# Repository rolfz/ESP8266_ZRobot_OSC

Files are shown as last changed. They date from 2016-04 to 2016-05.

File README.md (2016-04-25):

# ESP8266_ZRobot_OSC

EPS8266 based Robot with OSC based remote control. Robot can be controlled by iPhone or Smartphone, both config files are included.
The robot was based on FTobler Thingiverse 3d design http://www.thingiverse.com/thing:1230244

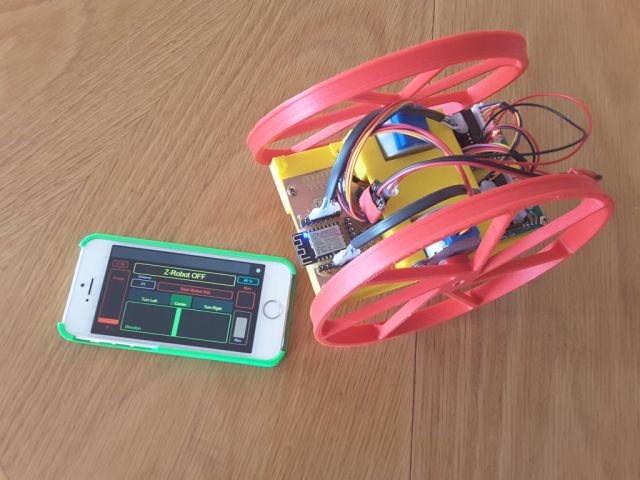
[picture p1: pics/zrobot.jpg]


Functionality: The robot code was basically made to test the TOUCHOSC interface. OSC allows to communicate both 
	ways between ESP8266 and a smart-phone. All code runs on the ESP module (No Arduino Hardware required).
- "Speed" cursor will define the speed of the step motors advance.
- "Direction" cursor adds or deducts a value from the speed making the robot turn left-right
- "Reverse" button inverses the motor rotation = reverse the engine direction like a car.
- 3 buttons "Turn Left, Center, Turn right" are preprogrammed directions for the robot
- "RUN" button will start the engine and also stop everything if cancelled.
- One status line is used to send instructions to the pilot
- One distance message box will indicate the distance to the next object (to be implemented).
- Current time and Smartphone battery are shown on the display

### Basic ideas, origin of the project:

- ftobler 3d files printed on Lulzbot TAZ4 printer.
- two 28byj-48 stepper motors with driver circuit from ebay
- ESP8266 12E module
	
###Changes, additions:

- ESP was programmed with Arduino based environment and ESP plug-in
- Accelstepper library (http://www.airspayce.com/mikem/arduino/AccelStepper/).
- Tutorial can be found here: (https://www.pjrc.com/teensy/td_libs_AccelStepper.html).
- LV-MAXSonar-EZ0 from Sparkfun
- self made board to hold the ESP module, with 2 push buttons for reset and setting programming mode, 
  led and connectors for the peripherals.
- Alternative battery holder to hold a 2S Lipo
- Alternative motor connections to simplify the wiring on the self made board.

### TouchOSC:

I discovered this app by accident when I looked at B-Robot and similar projects. Some tests made with 
Blynk which looks even more attractive made visible the current advantage of OSC! Easy implementation,
easy to use windows application to create the GUI, easy to load on a second or alternative platform 
and sizable widgets which are not yet possible on Blynk made me keep OSC for this project. Maybe I 
missed something on Blynk, at least it was not immediately visible that the features I missed where 
available. TouchOSC design tool is available for free from http://hexler.net/software/touchosc, you 
will need to pay for the user interface you download on your phone or tablet.

My current TouchOSC design:

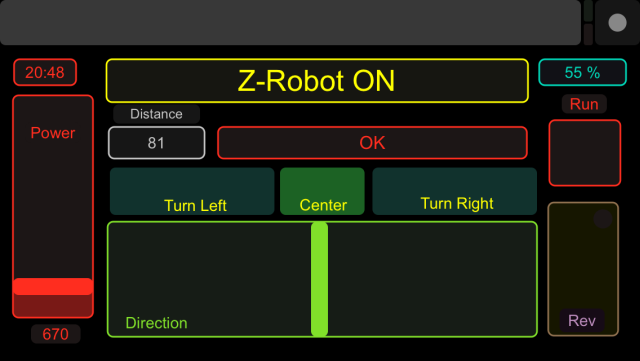
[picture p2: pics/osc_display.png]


OSC config: 
----------
Simple-Z-Robot-Iphone5.touchosc
Simple-Z-Robot-Samsung.touchosc
	
Code:
----
ESP8266_ZRobot_OSC.ino includes all Zrobot specific code.

Schematic:
---------
[schematic.pdf](schematic.pdf) and eagle files

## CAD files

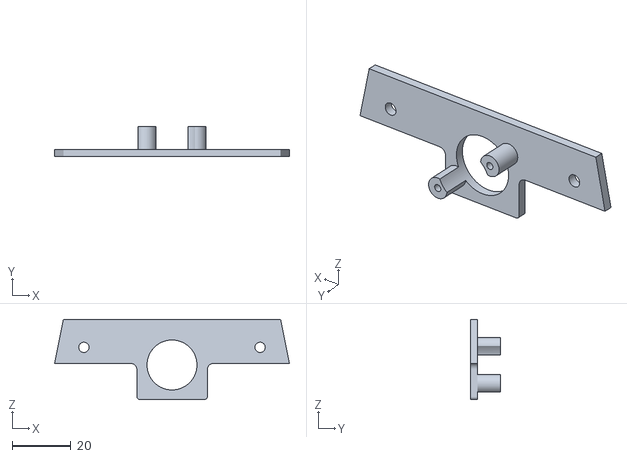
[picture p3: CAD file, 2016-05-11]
hardware/Ultrasonic_mounting.stl
80.0 x 10.3 x 27.3

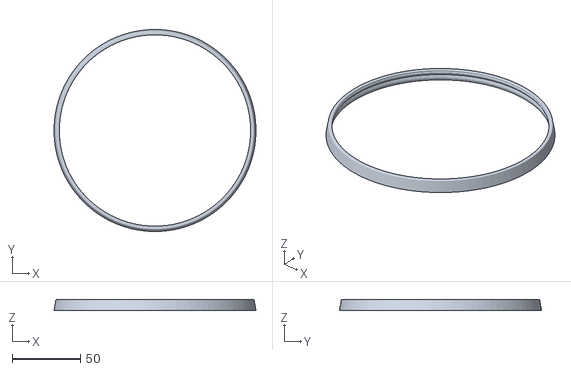
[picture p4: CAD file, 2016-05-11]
hardware/tyre_ninja.v2.stl
147.9 x 147.9 x 8.31

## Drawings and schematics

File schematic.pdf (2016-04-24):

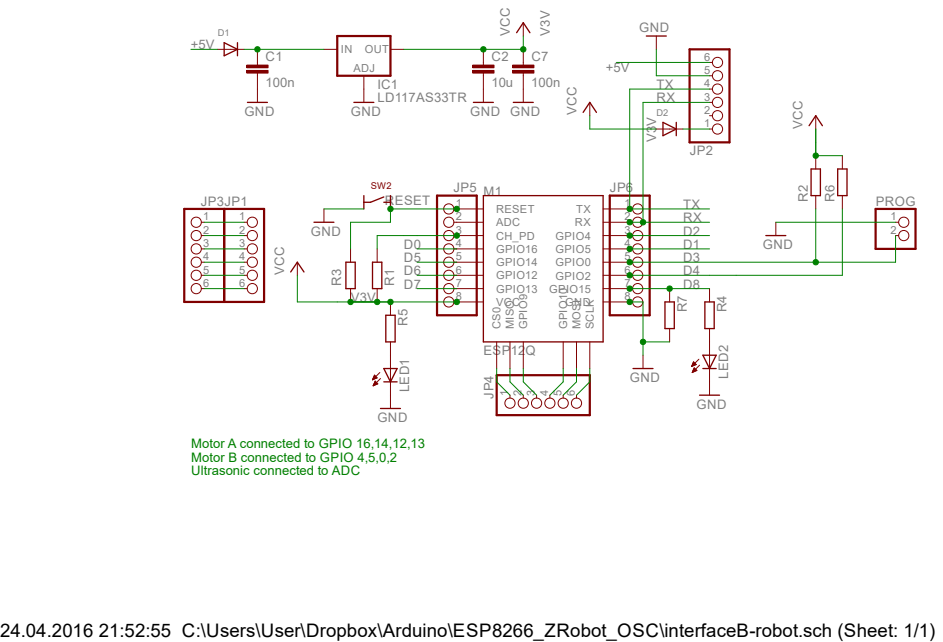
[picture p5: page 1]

Motor B connected to GPIO 4,5,0,2
Ultrasonic connected to ADC

24.04.2016 21:52:55 C:\Users\User\Dropbox\Arduino\ESP8266_ZRobot_OSC\interfaceB-robot.sch (Sheet: 1/1)

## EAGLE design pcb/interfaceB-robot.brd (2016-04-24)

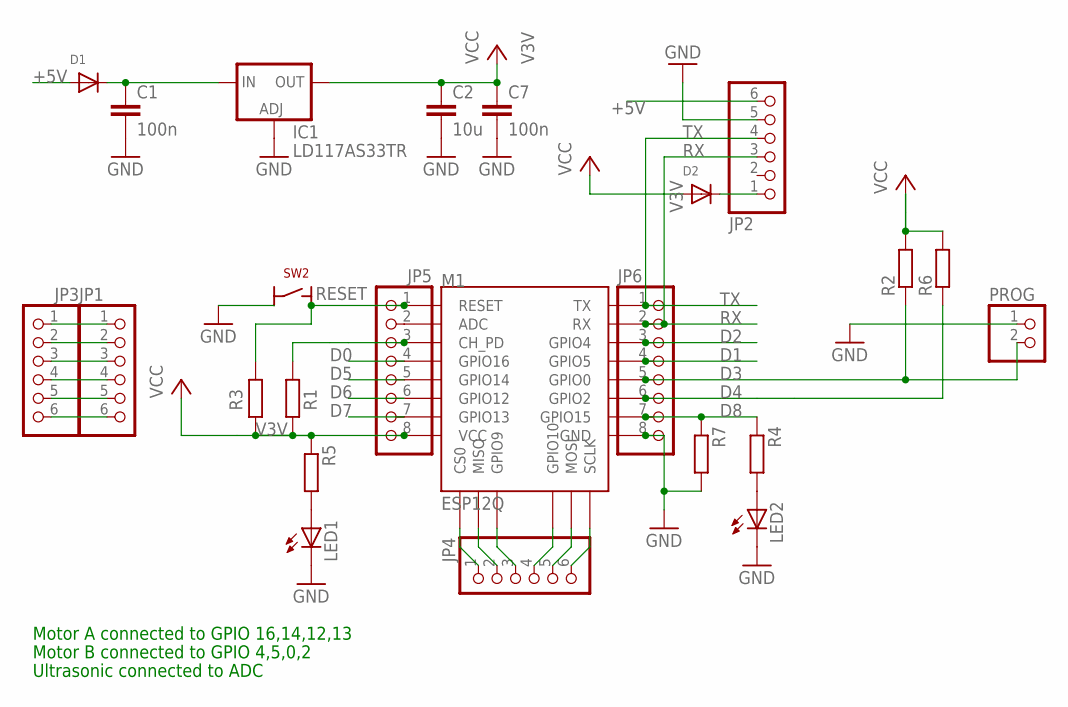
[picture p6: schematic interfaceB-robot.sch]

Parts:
C1: 100n; C1206K
C2: 10u; C1206K
C7: 100n; C0805
D1, D2: DIODE_SOD-123FL; SOD-123FL
IC1: LD117AS33TR; SOT223
JP1, JP2, JP3, JP4: PINHD-1X6; 1X06
JP5, JP6: PINHD-1X8; 1X08
LED1, LED2: LEDCHIPLED_0805; CHIPLED_0805
M1: ESP12Q
PROG: PINHD-1X2; 1X02
R1, R3: R-EU_R1206; R1206
R2, R4, R5, R6, R7: R-EU_R0805; R0805
SW2: SW4; SW45-65

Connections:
+5V: D1.A, JP2.6
D0: JP5.4, M1.GPIO16
D1: JP6.4, M1.GPIO5
D2: JP6.3, M1.GPIO4
D3: JP6.5, M1.GPIO0, PROG.2, R2.1
D4: JP6.6, M1.GPIO2, R6.1
D5: JP5.5, M1.GPIO14
D6: JP5.6, M1.GPIO12
D7: JP5.7, M1.GPIO13
D8: JP6.7, M1.GPIO15, R4.1, R7.1
GND: C1.2, C2.2, C7.2, IC1.1 (ADJ), JP2.5, JP6.8, LED1.C, LED2.C, M1.GND, PROG.1, R7.2, SW2.4
unnamed: C1.1, D1.C, IC1.3 (IN)
unnamed: JP5.2, M1.ADC
unnamed: JP1.1, JP3.1
unnamed: D2.C, JP2.1
unnamed: JP1.2, JP3.2
unnamed: JP1.3, JP3.3
unnamed: JP1.4, JP3.4
unnamed: JP1.5, JP3.5
unnamed: JP1.6, JP3.6
unnamed: LED1.A, R5.2
unnamed: LED2.A, R4.2
unnamed: JP4.1, M1.CS0
unnamed: JP4.2, M1.MISO
unnamed: JP4.3, M1.GPIO9
unnamed: JP4.4, M1.GPIO10
unnamed: JP4.5, M1.MOSI
unnamed: JP4.6, M1.SCLK
PD: JP5.3, M1.CH_PD, R1.1
RESET: JP5.1, M1.RESET, R3.1, SW2.2 (S)
RX: JP2.3, JP6.2, M1.RX
TX: JP2.4, JP6.1, M1.TX
V3V: C2.1, C7.1, D2.A, IC1.4 (OUT), JP5.8, M1.VCC, R1.2, R2.2, R3.2, R5.1, R6.2

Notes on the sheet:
Motor A connected to GPIO 16,14,12,13
Motor B connected to GPIO 4,5,0,2
Ultrasonic connected to ADC

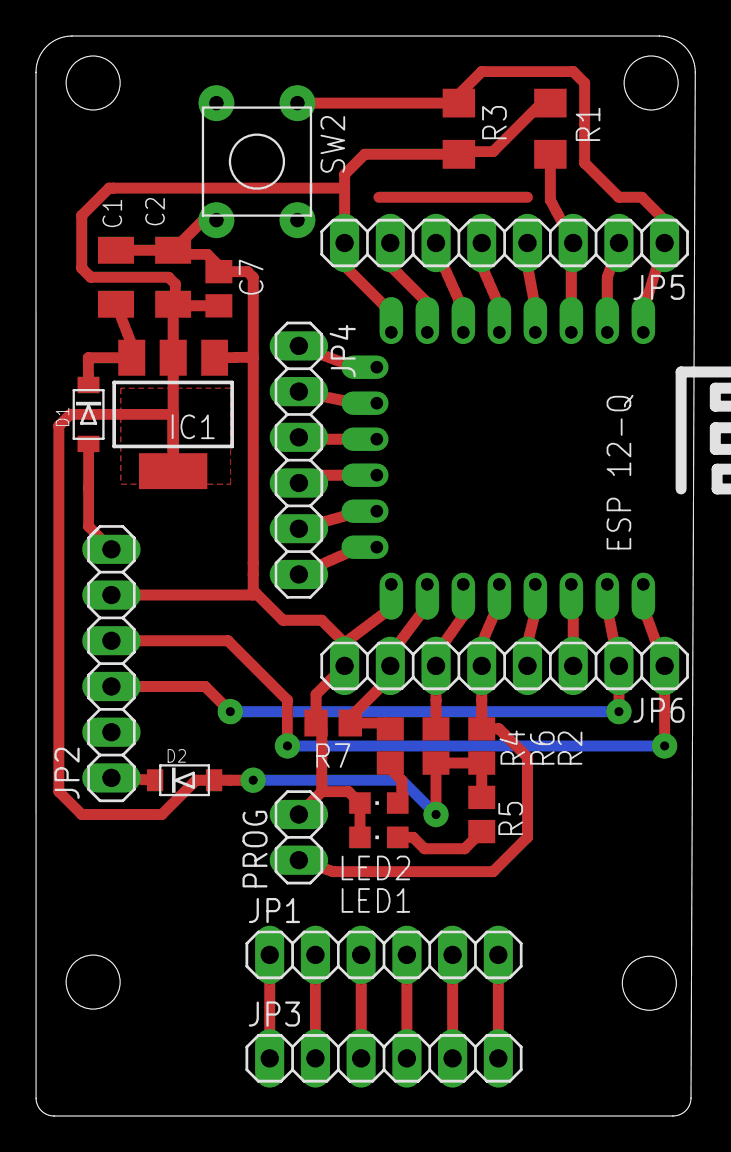
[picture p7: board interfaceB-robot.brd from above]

Board: 2 copper layers, 36.6 x 60.0 mm, 24 parts (0 on the bottom side), 33 nets.

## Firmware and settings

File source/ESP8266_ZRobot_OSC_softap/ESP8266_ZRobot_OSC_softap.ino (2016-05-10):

/*---------------------------------------------------------------------------------------------

  Open Sound Control (OSC) library for the ESP8266

  Example for receiving open sound control (OSC) bundles on the ESP8266
  Send integers '0' or '1' to the address "/led" to turn on/off the built-in LED of the esp8266.

  This example code is in the public domain.
http://42bots.com/tutorials/28byj-48-stepper-motor-with-uln2003-driver-and-arduino-uno/


  Code based on OSC template, modified for 2 wheel robot by Rolf Ziegler, May 2016
--------------------------------------------------------------------------------------------- */
#define SOFTAP

#include <ESP8266WiFi.h>
#include <WiFiUdp.h>

#include <OSCMessage.h>
#include <OSCBundle.h>
#include <OSCData.h>

#include <AccelStepper.h>

#ifdef SOFTAP
#include <WifiClient.h>
//#include <ESP8266WebServer.h>

//ESP8266WebServer server(80);
char ssid[] = "ZROBOT";                  // your network SSID (name)
//char pass[] = "xxx";               // your network password
#else
char ssid[] = "SSID";          // your network SSID (name)
char pass[] = "password";               // your network password
#endif

// UDP and communication defs  
char packetBuffer[UDP_TX_PACKET_MAX_SIZE]; //buffer to hold incoming packet,

// A UDP instance to let us send and receive packets over UDP
WiFiUDP Udp;

const IPAddress outIp(192,168,0,1);        // remote IP (not needed for receive)
const unsigned int outPort = 9999;          // remote port (not needed for receive)
const unsigned int inPort = 8888;        // local port to listen for UDP packets (here's where we send the packets)

int LED_PIN =  15;       //pin 13 on Arduino Uno. Pin 6 on a Teensy++2

// analog input for Disance sensor  
int SENSOR_PIN = A0;

OSCErrorCode error;
unsigned int ledState = LOW;              // LOW means led is *off*
unsigned int runit = 0;
int pwrval=0;
int dirval=0;
int revval=0; // reverse motors = 1

// Step motor defs
// change this to your motor if not NEMA-17 200 step
#define STEPS_PER_MREV 32  // Max steps for one revolution
#define STEPS_PER_OREV 32*64  // 2048 steps per rev
#define RPM 60     // Max RPM
#define DELAY 1    // Delay to allow Wifi to work
#define MAX_SPEED 1000.0

#define HALFSTEP 8
// Motor pin definitions
#define mPin11  2    //D4  IN1 on the ULN2003 driver 1
#define mPin12  4    //D3  IN2 on the ULN2003 driver 1
#define mPin13  0    //D2  IN3 on the ULN2003 driver 1
#define mPin14  5    //D1  IN4 on the ULN2003 driver 1

#define mPin21  13   //D0   IN1 on the ULN2003 driver 1
#define mPin22  14   //D5   IN2 on the ULN2003 driver 1
#define mPin23  12   //D6   IN3 on the ULN2003 driver 1
#define mPin24  16   //D8   IN4 on the ULN2003 driver 1

// GPIO Pins for Motor Driver board
AccelStepper Lstepper(HALFSTEP, mPin21,mPin22,mPin23,mPin24);
AccelStepper Rstepper(HALFSTEP, mPin11,mPin12,mPin13,mPin14);

// commands
// stepLeft.step(nr of steps)
// stepLeft.setSpeed(Long whatspeed)

//---------------------- Init Code --------------------------------------------
void setup() {
  
//  pinMode(BUILTIN_LED, OUTPUT);
  pinMode(LED_PIN, OUTPUT);
  
//  digitalWrite(BUILTIN_LED, ledState);    // turn *on* led

// setup ADC
//  ESP.ADC_MODE(ADC_VCC);

// setup UART
  Serial.begin(115200);
  Serial.println();
  Serial.println();

  // Connect to WiFi network
  #ifdef SOFTAP
   Serial.print("Please connect to Robot on AP ");
   Serial.println(ssid);
//   Serial.println("Password = " "pass""");

//    WiFi.softAP(ssid,pass);
      WiFi.softAP(ssid);
    
    IPAddress myIP = WiFi.softAPIP();
    Serial.print("AP IP address: ");
    Serial.println(myIP);

//    WiFi.mode(WIFI_STA);
    Serial.println("HTTP server started");

    
  #else
    Serial.print("Connecting to ");
    Serial.println(ssid);
    WiFi.begin(ssid, pass);
    while (WiFi.status() != WL_CONNECTED) {
    delay(500);
    Serial.print(".");
    }
    Serial.println("");
    Serial.println("WiFi connected");
    Serial.println("IP address: ");
    Serial.println(WiFi.localIP());
   
  #endif
  

  
//---------------- UDP start ------------------------------------------

  Udp.begin(inPort);
  Serial.println("UDP server Started");
  Serial.print("Local port: ");
  Serial.println(inPort);

 while(!Udp.available()){
   delay(500);
  Serial.print(">");
 }
  
// init stepper
  // Set default speed to Max (doesn't move motor)
  Lstepper.setMaxSpeed(MAX_SPEED);
  Lstepper.move(1);  // I found this necessary
  Lstepper.setSpeed(0);

  Rstepper.setMaxSpeed(MAX_SPEED);
  Rstepper.move(-1);  // I found this necessary
  Rstepper.setSpeed(0);

}

//------------------------ Functions --------------------------------------


void runCmd(OSCMessage &msg, int addrOffset ){

  runit = msg.getFloat(0);
  OSCBundle msgOUT;

  Serial.print("Robot ");
  
  if(runit==1)
  {  Serial.println("ON");
     msgOUT.add("/1/Logo").add("Z-Robot ON");
     digitalWrite(LED_PIN, 1);
     msgOUT.add("/1/Msg").add("OK");
  }
  else
  {
    Serial.println("OFF");
     msgOUT.add("/1/Logo").add("Z-Robot OFF");
     // put power cursor and value to 0
     msgOUT.add("/1/Pwr").add(0);
    // switch off motor power
     msgOUT.add("/1/PwrVal").add(0);
     pwrval=0;
     // and center the motor direction
     msgOUT.add("/1/Dir").add(0);
     dirval=0;
     digitalWrite(LED_PIN, 0);
     msgOUT.add("/1/Msg").add("OK");
  }

  Udp.beginPacket(Udp.remoteIP(), outPort);
  msgOUT.send(Udp); // send the bytes
  Udp.endPacket(); // mark the end of the OSC Packet
  msgOUT.empty(); // free space occupied by message
}

void dirCmd(OSCMessage &msg, int addrOffset){
  
  OSCBundle msgOUT;
  
  if(runit)
  {
    // stop reverse
  revval = 0;
  msgOUT.add("/1/Rev").add(revval);

  dirval = (int) msg.getFloat(0);
  msgOUT.add("/1/Msg").add("OK"); 
  Serial.print("Dir : ");
  Serial.println(dirval);
  
  }
  else
  {
 // and we bring back the cursor to central place
  Serial.println("Robot OFF !!");
  dirval=0;

  msgOUT.add("/1/Dir").add(dirval);
  msgOUT.add("/1/Msg").add("Start Robot first"); 
  }
  Udp.beginPacket(Udp.remoteIP(), outPort);
  msgOUT.send(Udp); // send the bytes
  Udp.endPacket(); // mark the end of the OSC Packet
  msgOUT.empty(); // free space occupied by message
  
}

void cenCmd(OSCMessage &msg, int addrOffset){
  
  dirval = 0;
  OSCMessage msgOUT("/1/Dir");
  msgOUT.add(dirval);
  Serial.print("Center Dir = ");
  Serial.println(dirval);
  
  Udp.beginPacket(Udp.remoteIP(), outPort);
  msgOUT.send(Udp); // send the bytes
  Udp.endPacket(); // mark the end of the OSC Packet
  msgOUT.empty(); // free space occupied by message

}

void revCmd(OSCMessage &msg, int addrOffset){
  
//  OSCMessage msgOUT("/1/RevLed");
  revval = (int) msg.getFloat(0);
//  msgOUT.add(revval);
  
//  Serial.print("Pwr : ");
  Serial.println("reverse");
  /*
  Udp.beginPacket(Udp.remoteIP(), outPort);
  msgOUT.send(Udp); // send the bytes
  Udp.endPacket(); // mark the end of the OSC Packet
  msgOUT.empty(); // free space occupied by message
*/
}

void stpCmd(OSCMessage &msg, int addrOffset){
  
  OSCBundle msgOUT;
  if(runit)
  {
  pwrval = 0;
  dirval = 0;
  msgOUT.add("/1/Pwr").add(pwrval);
  msgOUT.add("/1/PwrVal").add(pwrval);
  msgOUT.add("/1/Msg").add("Stopped");
  msgOUT.add("/1/Dir").add(dirval);

  Serial.println("Stopped");

  }

}

// add Tleft Tright

void tLeftCmd(OSCMessage &msg, int addrOffset){

  OSCBundle msgOUT;
  if(runit)
  {
  // stop reverse
  revval = 0;
  msgOUT.add("/1/Rev").add(revval);
  
  pwrval = 200;
  msgOUT.add("/1/PwrVal").add(pwrval);
  dirval = -200;
  msgOUT.add("/1/Dir").add(dirval);
  msgOUT.add("/1/Msg").add("OK");
  }
  else
  {
  msgOUT.add("/1/Msg").add("Start Robot first");
  }
  Udp.beginPacket(Udp.remoteIP(), outPort);
  msgOUT.send(Udp); // send the bytes
  Udp.endPacket(); // mark the end of the OSC Packet
  msgOUT.empty(); // free space occupied by message
}

void tRightCmd(OSCMessage &msg, int addrOffset){

  OSCBundle msgOUT;
 
 if(runit){
  // stop reverse
  revval = 0;
  msgOUT.add("/1/Rev").add(revval);

  pwrval = 200;
  msgOUT.add("/1/PwrVal").add(pwrval);
  dirval = 200;
  msgOUT.add("/1/Dir").add(dirval);
  msgOUT.add("/1/Msg").add("OK");
 }
 else
 {
  msgOUT.add("/1/Msg").add("Start Robot first");
 }
  Udp.beginPacket(Udp.remoteIP(), outPort);
  msgOUT.send(Udp); // send the bytes
  Udp.endPacket(); // mark the end of the OSC Packet
  msgOUT.empty(); // free space occupied by message
}

void pwrCmd(OSCMessage &msg, int addrOffset){
 
  OSCBundle msgOUT;
  if(runit)
  {
  pwrval = (int) msg.getFloat(0);
  msgOUT.add("/1/PwrVal").add(pwrval);
  msgOUT.add("/1/Msg").add("OK");

  Serial.print("Pwr : ");
  Serial.println(pwrval);

  }
  else
  {
    Serial.println("Robot OFF !!");
    pwrval=0;
    msgOUT.add("/1/Pwr").add(pwrval);
    msgOUT.add("/1/PwrVal").add(pwrval);
    msgOUT.add("/1/Msg").add("Start Robot first");
  }
  
  Udp.beginPacket(Udp.remoteIP(), outPort);
  msgOUT.send(Udp); // send the bytes
  Udp.endPacket(); // mark the end of the OSC Packet
  msgOUT.empty(); // free space occupied by message
}

void updateRadar(int radarDist){
  
  OSCMessage msgOUT("/1/Rfront"); // Rback
  msgOUT.add(int(radarDist));

  Udp.beginPacket(Udp.remoteIP(), outPort);
  msgOUT.send(Udp); // send the bytes
  Udp.endPacket(); // mark the end of the OSC Packet
  msgOUT.empty(); // free space occupied by message
}

void OSCMsgReceive(void){
  OSCMessage msgIN;
  int size;
  if((size = Udp.parsePacket())>0){

//#define TRACE_OSC

    // dump date to terminal for debugging
    #ifdef TRACE_OSC
    Udp.read(packetBuffer,UDP_TX_PACKET_MAX_SIZE);
    Serial.print("Contents: ");
    Serial.println(packetBuffer);
    #endif
    
    // read and interprete data
    while(size--) msgIN.fill(Udp.read());
     
    if(!msgIN.hasError()){
      msgIN.route("/1/Run",runCmd);
      msgIN.route("/1/Dir",dirCmd);
      msgIN.route("/1/Tleft",tLeftCmd);
      msgIN.route("/1/Tright",tRightCmd);
      msgIN.route("/1/Cen",cenCmd);
      msgIN.route("/1/Rev",revCmd);
      msgIN.route("/1/Pwr",pwrCmd);
      msgIN.route("/1/Stp",stpCmd);
    }
  }
}

//---------------------- Main code stats here----------------------------------
unsigned long lastMillis2; // used to delay ADC conversion to avoid hanging up WIFI
unsigned int avDistance=0; // used to average distance over 10 samples (low-pass)

void loop(void){
  
  // handle wifi client
//  server.handleClient();
  //process received messages
  OSCMsgReceive();

// read sensor
unsigned long CurrentMillis = millis();
// slow down ADC to keep wifi alive, we mesure every 10ms
  if (CurrentMillis - lastMillis2 > 10)
  {
    int rDistance=analogRead(SENSOR_PIN);
    updateRadar(rDistance);
    lastMillis2 = CurrentMillis;
    avDistance=(avDistance*9+rDistance)/10;
    updateRadar(avDistance);
//    Serial.println(avDistance);
  }

// we will use dirvalue and pwrvalue to run the robot
/* variables used from iPhone, smartphone
 *  dirval,direction 
 *  pwrval,power 
 *  
 */ 
 int mixL,mixR;
 
   mixL=pwrval+dirval;
   if(mixL>MAX_SPEED)mixL=MAX_SPEED;
   mixR=-(pwrval-dirval);
   if(mixR>MAX_SPEED)mixR=MAX_SPEED;
 
  if(revval==1) // we reverse the motor sense
    {
     mixL*=-1;
     mixR*=-1;
    }
     
  
  Lstepper.setSpeed(mixL);
  Rstepper.setSpeed(-mixR);

  if(runit){
   Lstepper.runSpeed();
   Rstepper.runSpeed();
  }
  else //we switched off the robot
  {
    Lstepper.stop();
    Rstepper.stop();
  }
 }

// end of code

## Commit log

2016-04-24 original PCB & Schematic
    [interfaceB-robot.brd, interfaceB-robot.sch]
2016-04-24 added schematic
    [interfaceB-robot.sch]
2016-04-24 reorganized files
    [interfaceB-robot.brd, interfaceB-robot.sch]
2016-04-25 Corrections made to include the reverse gear, also the pin assignement for the step motors was not correct, wiring needs to be 1324 and not 1234 (setup in the code). Code may need a little adjustment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
    [ESP8266_ZRobot_OSC.ino]
2016-04-25 reverse mode did not work
    [ESP8266_ZRobot_OSC.ino]
2016-04-26 renamed command calls, working on ADC mesure of Ultrasonic module, not yet ready. ESP8266 seems to have a problem with ADC, also mesuring it in the main loop at the same speed reduced the speed and i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
    [ESP8266_ZRobot_OSC.ino]
2016-05-10 Soft-AP version, some data sent back from OSC still do not update and need some more work. Robot control (ESP to mobile device) works fine.
2016-05-10 Added Stop button under Power Slider
2016-05-11 additional parts for 2 wheel robot, tyre printed with ninjaflex (print with scale x+y at 97%) and ultrasonic mounting front for LV-MaxSonar part
    [Ultrasonic_mounting.stl, tyre_ninja.v2.stl]
